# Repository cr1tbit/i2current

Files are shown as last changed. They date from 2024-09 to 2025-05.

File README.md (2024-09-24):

# I2Current powerboard

The Raison d'être of this board is to be a powerful, extensible, and affordable replacement for hotglueing a random powerbank into your next portable small-scale electronic project.

The largest benefit comes from the I2C interface - If, for example, a Raspberry Pi is powered with this board, it can actually check the battery state, if DC-jack is currently charging the device, or even see the power draw of other peripherals connected to this system.

The board is most useful for powering devices requiring peak power draw between 15W-60W.

For devices requiring less power, the cost overhead becomes a bit too much - alternative solutions on aliexpress, albeit not as much versatile, can cost less than $3 (this board costs ~$10, ordering 20 units from JLCPCB).

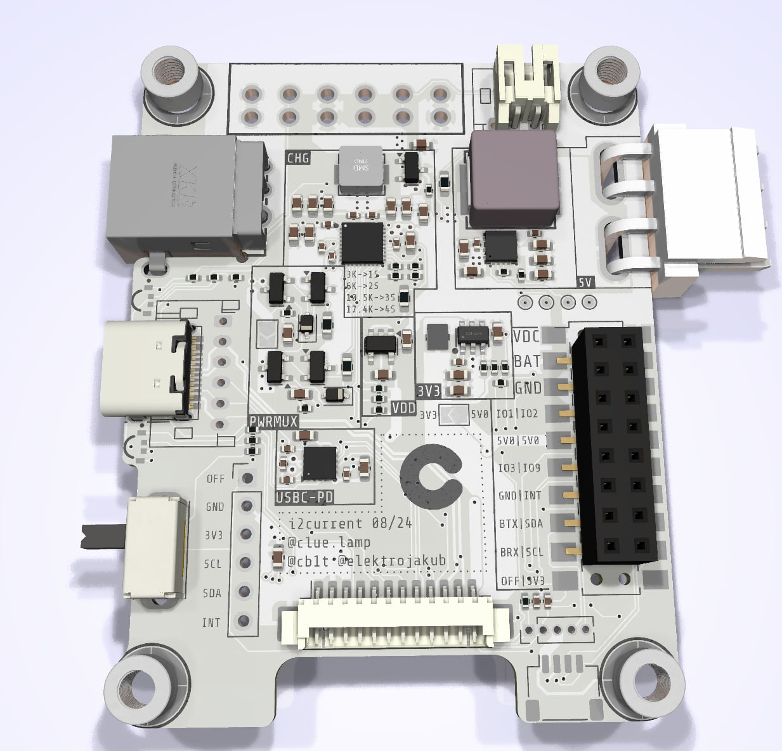
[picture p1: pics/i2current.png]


## Sub-components

### BQ25792 Li-Ion charger

Specs:

* 3.6-24V input, max 3A (realistically, ~60W)
* Input voltage independent from battery pack (buck-boost built-in)
* Input from USB-C and/or DC barrel jack.
* Can provide up to 3.33A@20V output to the same USB-C port
* can work with 1S-4S (cells in series)
* output current 5A (with 4 cells (~16V), up to ~80W output)
* Works properly without battery pack too (can work as buck-boost power supply)
* Many parameters configurable via i2c
* Various battery/input/output voltages/currents readout

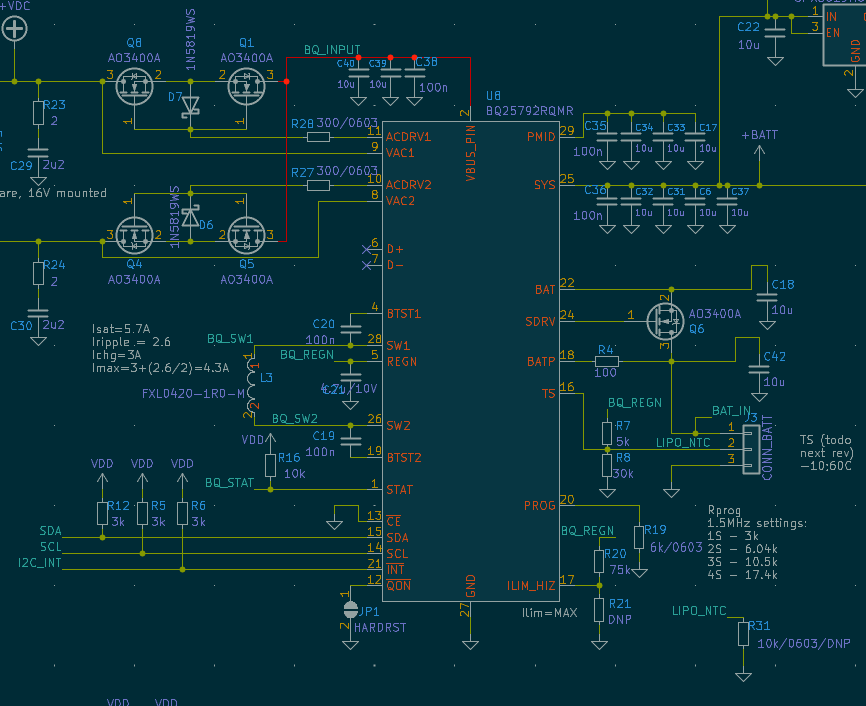
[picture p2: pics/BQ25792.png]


This charger is incredibly universal, costing around 1$ it provides versatility for many types of projects.

### TPS56637 5V output step-down converter

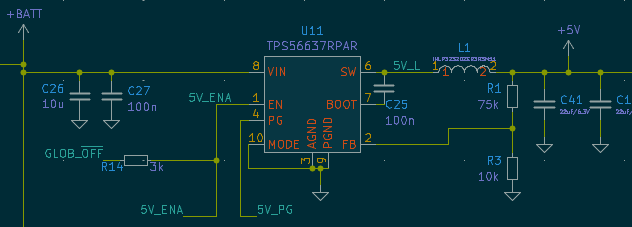
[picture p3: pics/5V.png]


It can provide up to 6A (30W) on output. However, it requires atleast 2S packet to be usable.

### MT2492 3V3 DC-DC

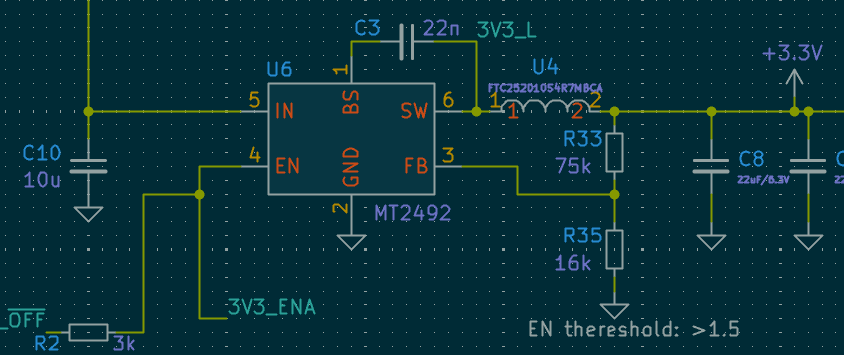
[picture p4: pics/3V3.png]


This converter supports optional built-in ESP32-C3 controller, and can also be accesed via output pins

### SPX3819M5-L-3-3 3V3 LDO

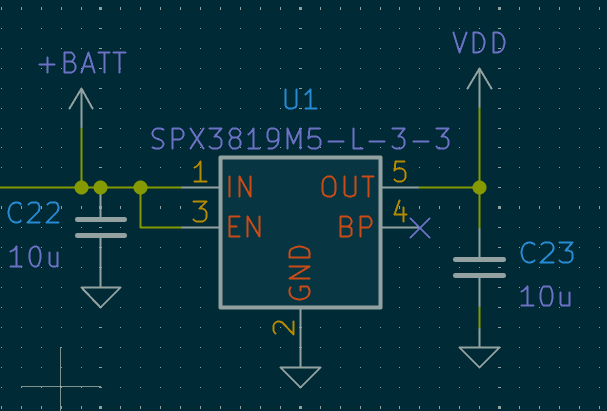
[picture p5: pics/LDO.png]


This low-power stabilizer provides power to onboard devices and some circuitry. It cannot be turned off, in contrast to 2 other converters.

### FUSB302B Power Delivery controller

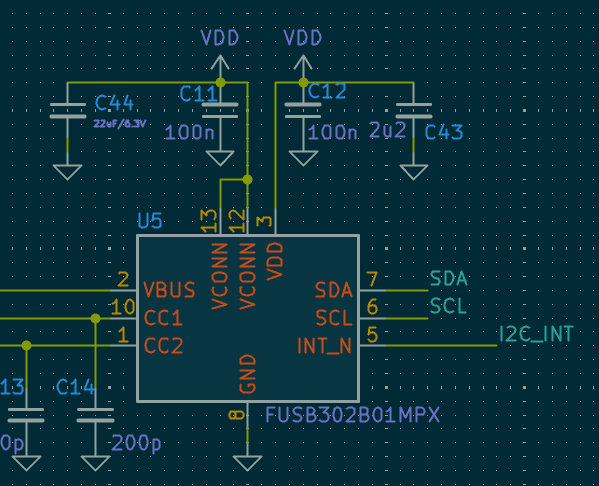
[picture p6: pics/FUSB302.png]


This device is controlled via i2c, and can be used to negotiate up to 5A/20V from compatible USB-C chargers.

Arduino library is available.

## Connectors

### Output 2.54 connector

This connector has been designed for low-profile goldpin socket connector (the male header actually goes through the holes in the PCB)

Shield can be designed, utilizing this connector.

### Picoblade connector

This connector is dedicated for devices, where a "master" board sits somewhere else in the system. 

### Battery connector

* Battery input
* NTC resistor input (every battery pack should contain one, more on that later)
* GND
* Battery output (coming from BQ charger, provides stable voltage when baterry is depleated or missing)
* GLOB_OFF (pin for external power-off switch)
* VDC_IN (same as from barrel jack input)

## More to come...

this board has many more fun quirks - I'll describe more details at a later date.

* optional mini front panel with OLED
* Passive-PoE input
* standalone 4-channel WLED controller
* USB data lanes passthrough for 2 connectors and built-in ESP32

#### Todo - document:

* Li-ion safety guide
* USB passthrough
* GLOB_OFF usage
* Pinout description for every connector
* 1S-4S config and limitations

## Sponsors

Developent of this board is supported by [Clue.lamp](https://www.instagram.com/clue.lamp/).

Check them out, the device looks really nice, and utilizes state-of-the-art electronic design for both wired and wireless usage :)

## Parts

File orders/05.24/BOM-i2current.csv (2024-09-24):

Comment | Designator | Footprint | LCSC
6k/0603 | R19 | R_0603_1608Metric_Pad0.98x0.95mm_HandSolder | C131439
FUSB302B01MPX | U5 | WQFN-14-1EP_2.5x2.5mm_P0.5mm_EP1.45x1.45mm | C132291
200p | C13,C14 | C_0402_1005Metric | C1530
22n | C3 | C_0402_1005Metric | C1532
2u2 | C29,C30,C43 | C_0603_1608Metric | C15849
USB_C_Receptacle_USB2.0 | J2 | USB_C_Receptacle_HRO_TYPE-C-31-M-12 | C165948
FXL0420-1R0-M | L3 | IND-SMD_L4.4-W4.2 | C167203
1N5819WS | D6,D7 | D_SOD-323 | C191023
4.7u/10V | C21 | C_0402_1005Metric | C19702
AO3400A | Q1,Q4,Q5,Q6,Q8 | SOT-23 | C20917
300/0603 | R27,R28 | R_0603_1608Metric_Pad0.98x0.95mm_HandSolder | C23025
100 | R11,R4 | R_0402_1005Metric | C25076
2 | R23,R24 | R_0402_1005Metric | C25092
30k | R8 | R_0402_1005Metric | C25553
10k | R10,R16,R3,R9 | R_0402_1005Metric | C25744
16k | R35 | R_0402_1005Metric | C25759
75k | R1,R20,R33 | R_0402_1005Metric | C25798
3k | R12,R14,R18,R2,R25,R29,R5,R6 | R_0402_1005Metric | C25890
5k | R7 | R_0402_1005Metric | C25905
Conn_01x12_MountingPin | J4 | Molex_PicoBlade_53261-1271_1x12-1MP_P1.25mm_Horizontal | C276921
BQ25792RQMR | U8 | QFN-29_L4.0-W4.0-P0.40-TL-BQ25792RQMR | C2862876
SMTSO3030CTJ | U10,U2,U3,U9 | SMD_BD5.6-D4.1 | C2915308
100n | C1,C11,C12,C19,C2,C20,C25,C27,C35,C36,C38 | C_0402_1005Metric | C307331
SW_SPDT | SW6 | SW_Slide_SPDT_Angled_CK_OS102011MA1Q | C393937
DC-C033D-5.5A-2.0 | DC1 | DC-IN-TH_DC-C033D-5.5A-2.5 | C500113
IHLP3232DZER3R3M11 | L1 | IND-SMD_L8.7-W8.2_IHLP-3232CZ | C511015
A-SP1102AR6GHC-A01-2C | U12,U13 | LED-SMD_4P-L3.0-W1.5_A-SP1102AR6GHC-A01-2C | C5160724
FTC252010S4R7MBCA | U4 | IND-SMD_L2.5-W2.0-VLS252012CX-150M | C5832360
22uF/6.3V | C15,C4,C41,C44,C8,C9 | C_0603_1608Metric | C59461
TPS56637RPAR | U11 | VQFN-HR-10_L3.0-W3.0_RPA | C841386
MT2492 | U6 | SOT-23-6_L2.9-W1.6-P0.95-LS2.8-BL | C89358
SPX3819M5-L-3-3 | U1 | SOT-23-5 | C9055
10u | C10,C17,C18,C22,C23,C26,C31,C32,C33,C34,C37,C39,C40,C42,C5,C6 | C_0603_1608Metric | C96446
PANEL_CONN | J8 | PinHeader_1x06_P2.54mm_Vertical
EXT_IFACE | J5 | 2x10_smdthrough
CONN_BATT | J3 | JST_PH_S3B-PH-K_1x03_P2.00mm_Horizontal
Conn_01x06 | J9 | JST_PH_S6B-PH-K_1x06_P2.00mm_Horizontal
Conn_01x05 | J6 | PinHeader_1x05_P1.27mm_Vertical
B4P | J1 | B4P_MATRIXPWR
DNP | R21 | R_0402_1005Metric
QWIIC | J10 | JST_SH_SM04B-SRSS-TB_1x04-1MP_P1.00mm_Horizontal
HARDRST | JP1 | SolderJumper-2_P1.3mm_Open_TrianglePad1.0x1.5mm
QWIIC | J11 | JST_SH_SM04B-SRSS-TB_1x04-1MP_P1.00mm_Horizontal
TestPoint | TP1 | TestPoint_Pad_D1.0mm
ESP32-C3-WROOM-02 | U7 | ESP32-C3-WROOM-02
TestPoint | TP3 | TestPoint_Pad_D1.0mm
TestPoint | TP2 | TestPoint_Pad_D1.0mm
JL15EDGA-38106G01 | CN1 | CONN-TH_6P-P3.81_JILN_JL15EDGA-38106G01
VBUS_DC | JP3 | SolderJumper-2_P1.3mm_Open_TrianglePad1.0x1.5mm
10k/0603/DNP | R31 | R_0603_1608Metric_Pad0.98x0.95mm_HandSolder
3V3_5V | JP4 | SolderJumper-2_P1.3mm_Open_TrianglePad1.0x1.5mm
TestPoint | TP4 | TestPoint_Pad_D1.0mm

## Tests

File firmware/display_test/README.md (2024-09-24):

# i2current firmware project

Not much to talk here for now. Tested utils:

* PD controller - negotiation works fine, but only if set up properly. In other case, it can cause the device to bootloop.
* BQ charger - the library provides only some of the features, but they seem to work fine.

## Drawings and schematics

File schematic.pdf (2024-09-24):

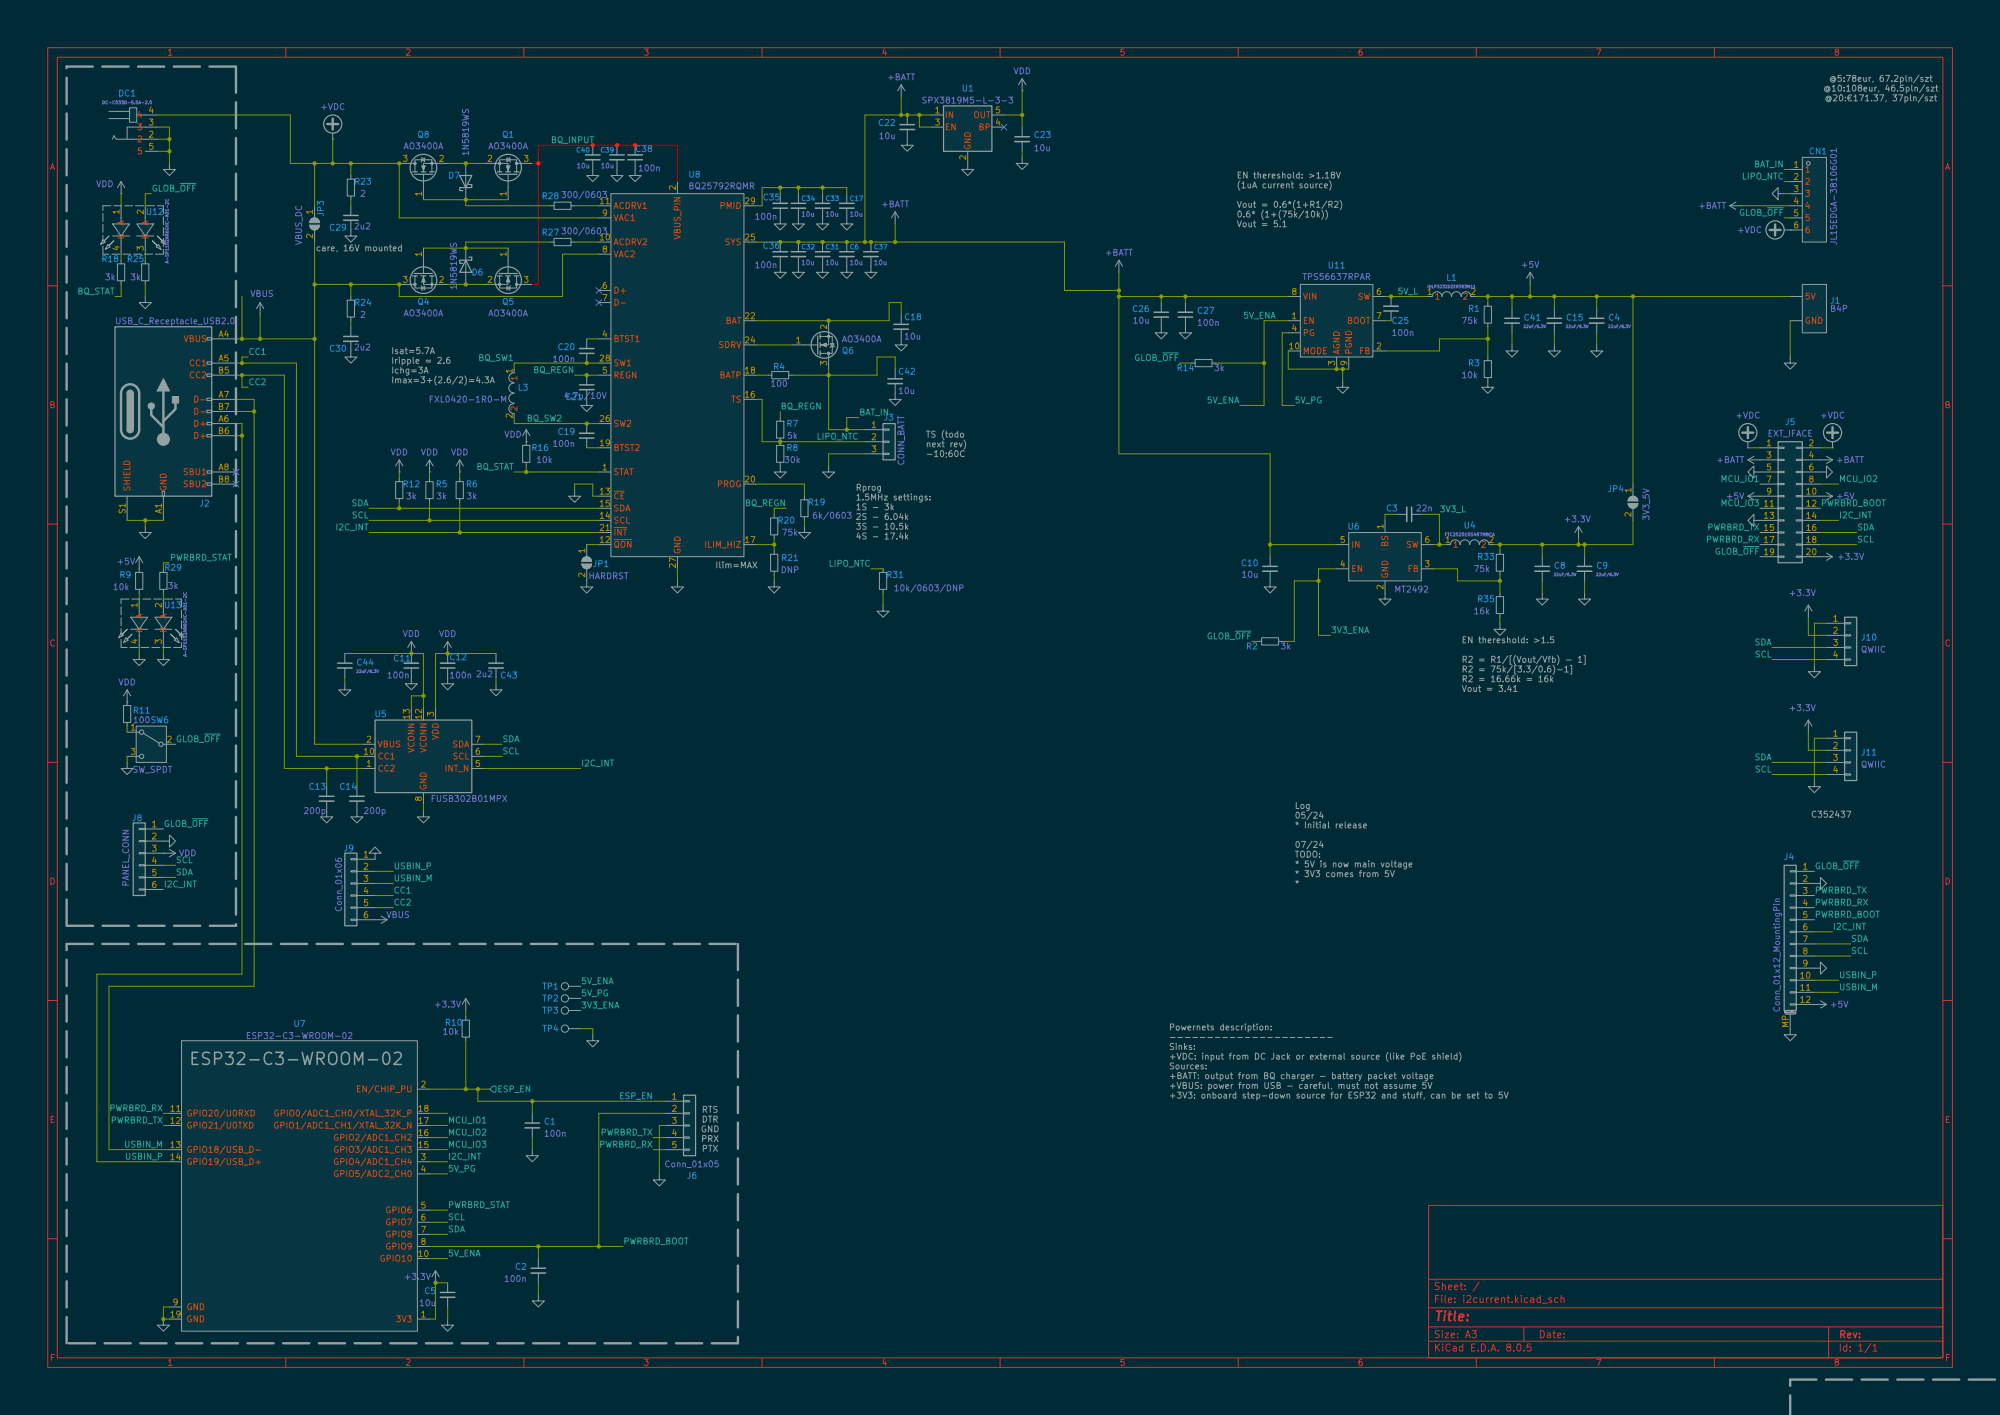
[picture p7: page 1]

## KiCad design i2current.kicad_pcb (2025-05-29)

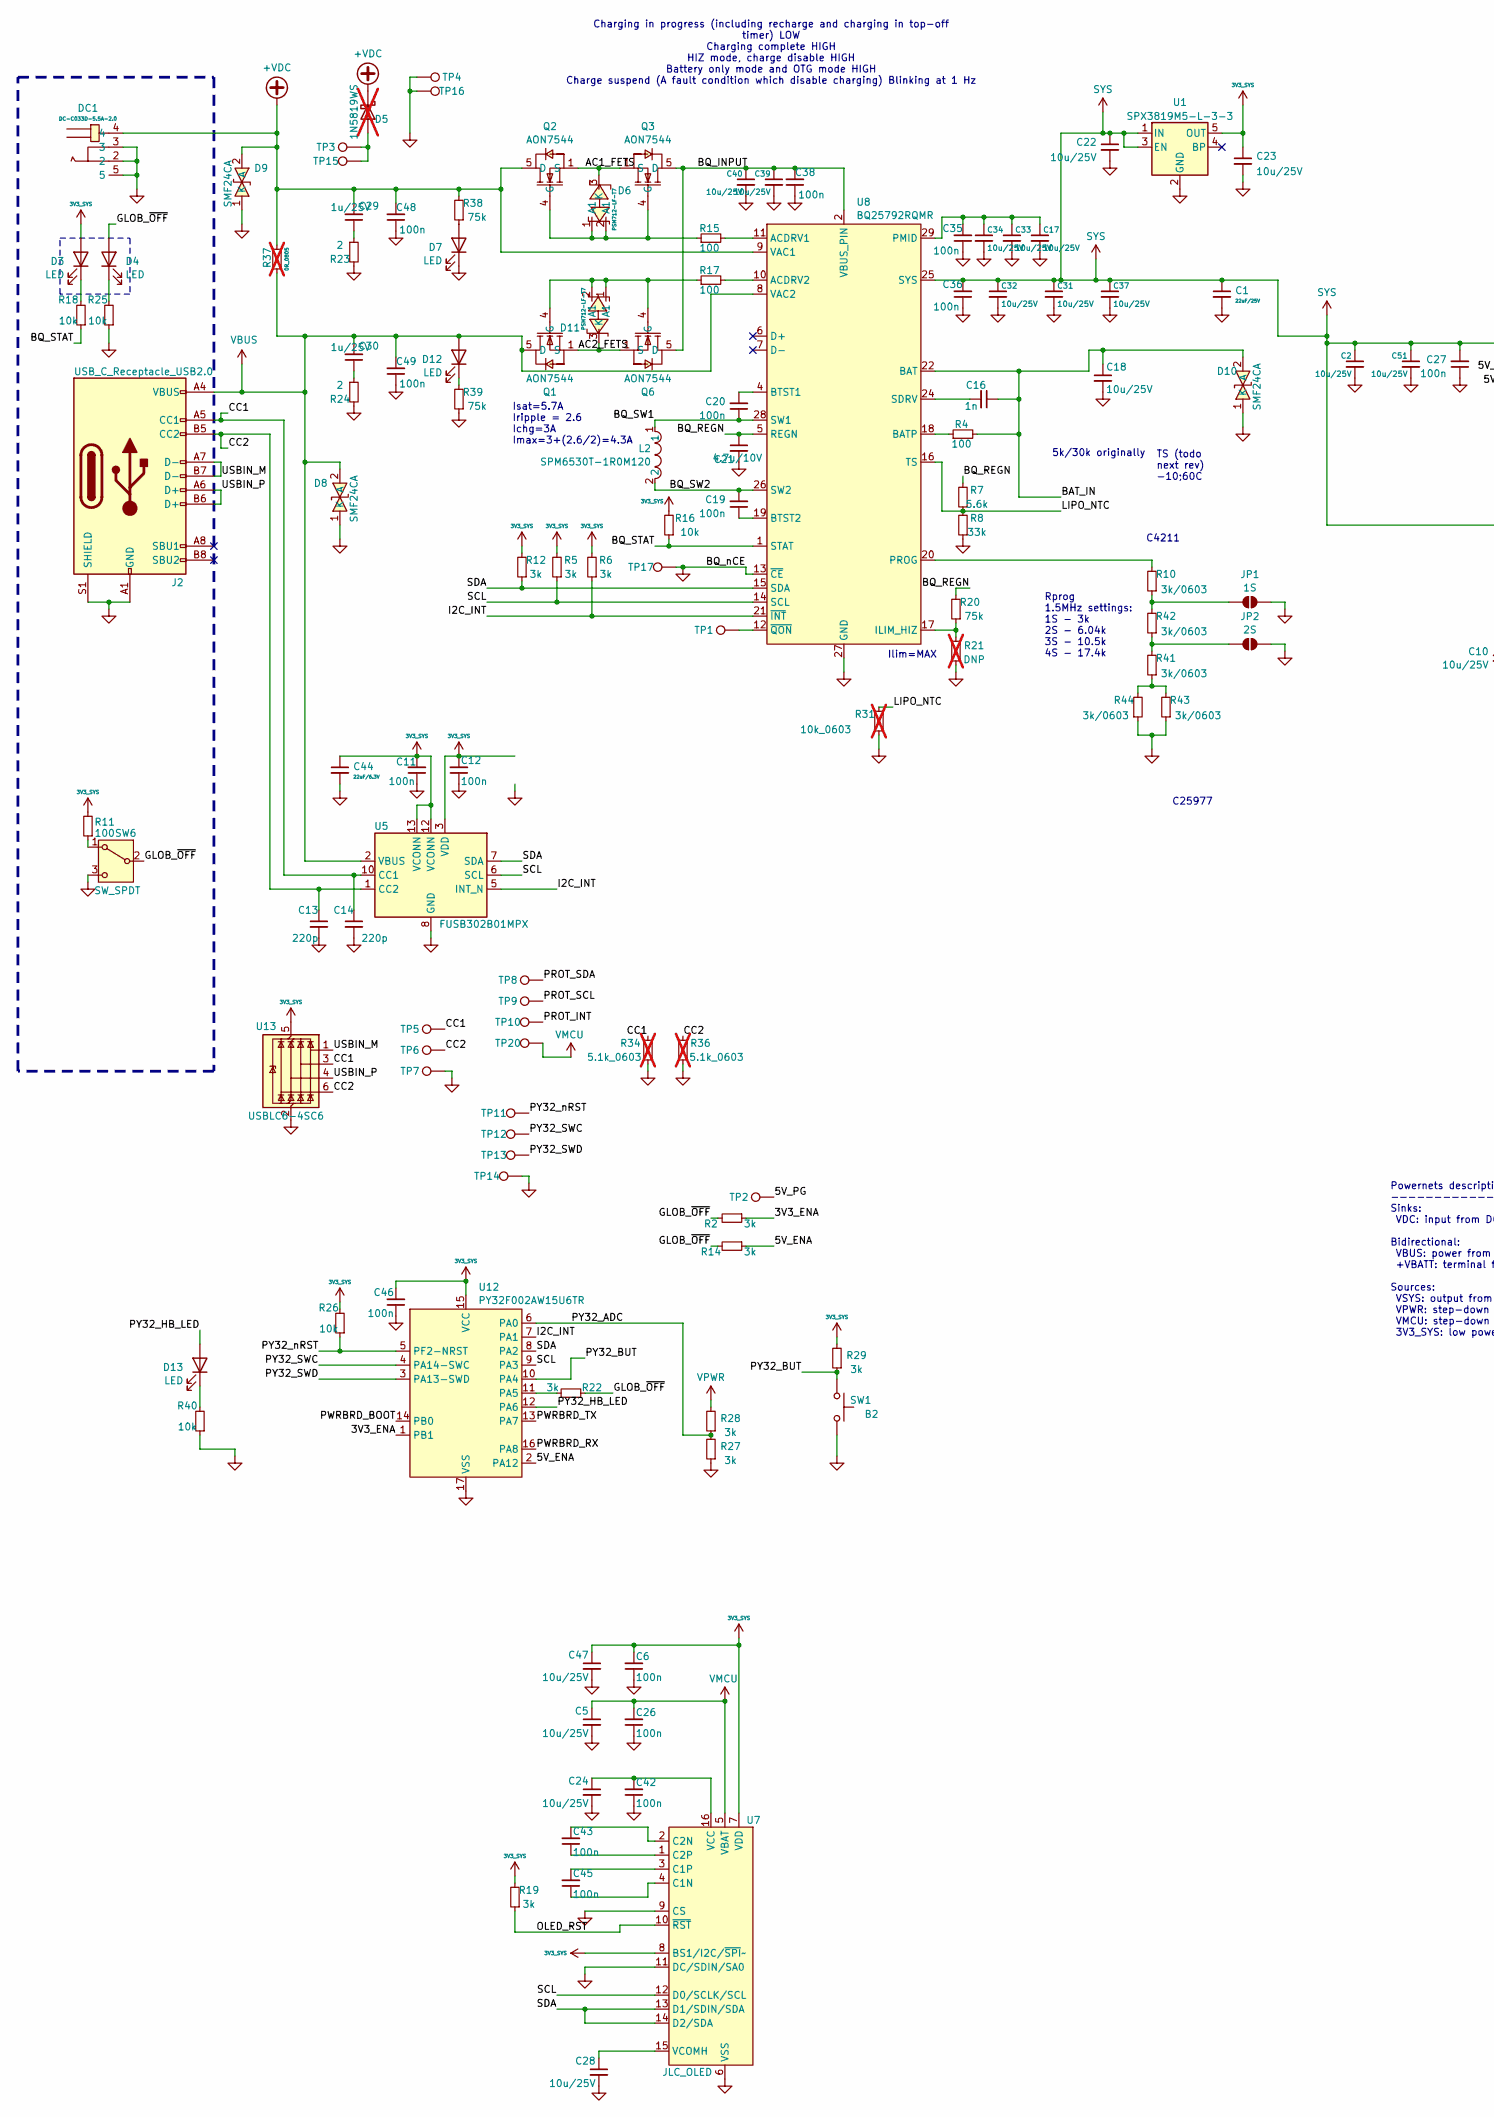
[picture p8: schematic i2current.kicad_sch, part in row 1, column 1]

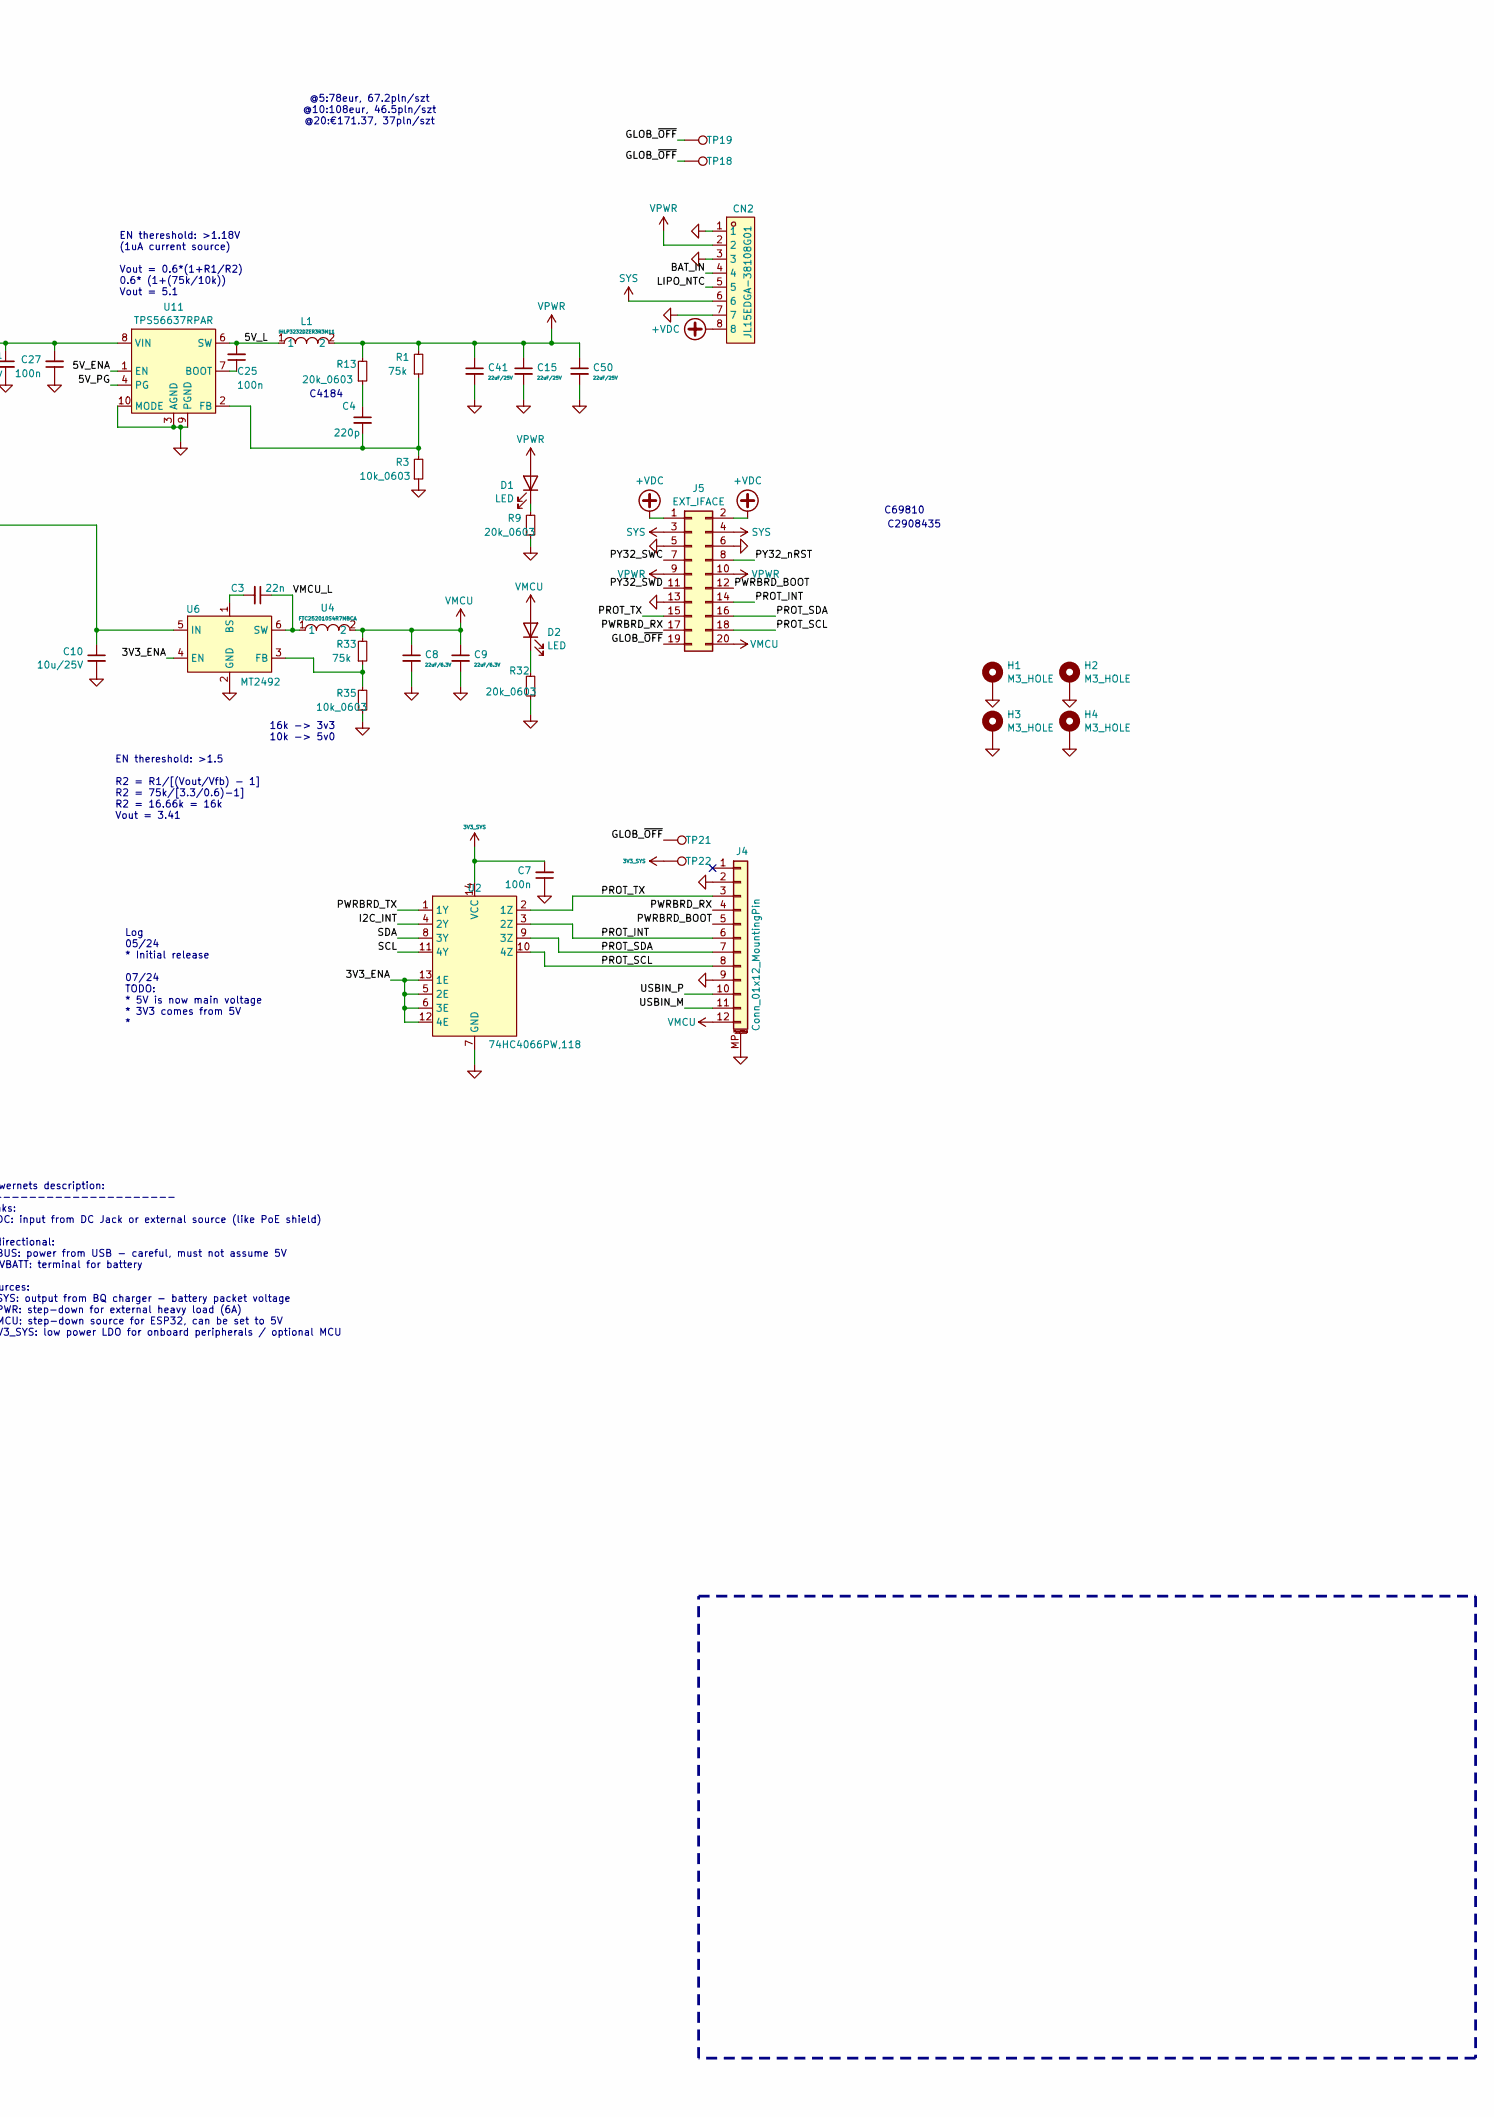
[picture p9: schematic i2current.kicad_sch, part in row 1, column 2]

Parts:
C1, C15, C41, C50: 22uF/25V; C_1206_3216Metric; LCSC C12891
C2, C5, C10, C17, C18, C22, C23, C24, C28, C31, C32, C33, C34, C37, C39, C40, C47, C51: 10u/25V; C_0603_1608Metric; LCSC C96446
C3: 22n; C_0402_1005Metric; LCSC C1532
C4, C13, C14: 220p; C_0402_1005Metric; LCSC C1530
C6, C7, C11, C12, C19, C20, C25, C26, C27, C35, C36, C38, C42, C43, C45, C46, C48, C49: 100n; C_0402_1005Metric; LCSC C307331
C8, C9, C44: 22uF/6.3V; C_0603_1608Metric; LCSC C59461
C16: 1n; C_0402_1005Metric; LCSC C1532
C21: 4.7u/10V; C_0402_1005Metric; LCSC C23733
C29, C30: 1u/25V; C_0603_1608Metric; LCSC C15849
CN2: JL15EDGA-38108G01; CONN-TH_8P-P3.81_JILN_JL15EDGA-38108G01; LCSC Part C2908436
D1, D2, D3, D4, D7, D12, D13: LED; LED_0603_1608Metric; LCSC C72038
D5: 1N5819WS; D_SOD-323; LCSC C191023; not fitted
D6, D11: PSM712-LF-T7; SOT-23-3_L3.0-W1.7-P0.95-LS2.9-BR; LCSC C32677
D8, D9, D10: SMF24CA; SOD-123FL_L2.7-W1.8-LS3.8-BI; LCSC C19077515
DC1: DC-C033D-5.5A-2.0; DC-IN-TH_DC-C033D-5.5A-2.5; LCSC C500113
H1, H2, H3, H4: M3_HOLE; MountingHole_3.2mm_LONGE
J2: USB_C_Receptacle_USB2.0; USB_C_Receptacle_HRO_TYPE-C-31-M-12; LCSC C165948
J4: Conn_01x12_MountingPin; Molex_PicoBlade_53261-1271_1x12-1MP_P1.25mm_Horizontal; LCSC C276921
J5: EXT_IFACE; SAMTEC_HLE-110-02-F-DV-BE-A
JP1: 1S; SolderJumper-2_P1.3mm_Open_TrianglePad1.0x1.5mm
JP2: 2S; SolderJumper-2_P1.3mm_Open_TrianglePad1.0x1.5mm
L1: IHLP3232DZER3R3M11; IND-SMD_L8.7-W8.2_IHLP-3232CZ; LCSC C511015
L2: SPM6530T-1R0M120; IND-SMD_L7.1-W6.5-P5.60; LCSC C87572
Q1, Q2, Q3, Q6: AON7544; DFN-8_L3.3-W3.3-P0.65-BL-2; LCSC C315567
R1, R20, R33, R38, R39: 75k; R_0603_1608Metric
R2, R5, R6, R12, R14, R19, R22, R27, R28, R29: 3k; R_0402_1005Metric
R3, R35: 10k_0603; R_0603_1608Metric
R4, R11, R15, R17: 100; R_0402_1005Metric
R7: 5.6k; R_0603_1608Metric
R8: 33k; R_0603_1608Metric
R9, R13, R32: 20k_0603; R_0603_1608Metric
R10, R41, R42, R43, R44: 3k/0603; R_0603_1608Metric
R16, R18, R25, R26, R40: 10k; R_0402_1005Metric
R21: DNP; R_0603_1608Metric; not fitted
R23, R24: 2; R_0603_1608Metric; LCSC C22939
R31: 10k_0603; R_0603_1608Metric; not fitted
R34, R36: 5.1k_0603; R_0603_1608Metric; not fitted
R37: 0R_0805; R_0805_2012Metric; not fitted
SW1: B2; SW_SPST_TL3342; LCSC C318884
SW6: SW_SPDT; SW_Slide_SPDT_Angled_CK_OS102011MA1Q; LCSC C393937
TP1, TP17, TP18, TP19, TP21, TP22: TestPoint; Nano_testpad_0.5x1.0mm
TP2, TP5, TP6, TP7, TP8, TP9, TP10, TP11, TP12, TP13, TP14, TP20: TestPoint; TestPoint_Pad_D1.0mm
TP3, TP4, TP15, TP16: TestPoint; TestPoint_Pad_D2.0mm
U1: SPX3819M5-L-3-3; SOT-23-5; LCSC C9055
U2: 74HC4066PW,118; TSSOP-14_L5.0-W4.4-P0.65-LS6.4-BL; LCSC C5650
U4: FTC252010S4R7MBCA; IND-SMD_L2.5-W2.0-VLS252012CX-150M; LCSC C5832360
U5: FUSB302B01MPX; WQFN-14-1EP_2.5x2.5mm_P0.5mm_EP1.45x1.45mm; LCSC C442699
U6: MT2492; SOT-23-6_L2.9-W1.6-P0.95-LS2.8-BL; LCSC C89358
U7: JLC_OLED; OLED-042-JLC
U8: BQ25792RQMR; QFN-29_L4.0-W4.0-P0.40-TL-BQ25792RQMR; LCSC C2862876
U11: TPS56637RPAR; VQFN-HR-10_L3.0-W3.0_RPA; LCSC C841386
U12: PY32F002AW15U6TR; TQFN-16-1EP_3x3mm_P0.5mm_EP1.6x1.6mm; LCSC C5291740
U13: USBLC6-4SC6; SOT-23-6; LCSC C5197386

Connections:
3V3_SYS: C6.2, C7.2, C11.2, C12.2, C23.1, C44.1, C46.2, C47.1, D3.2 (A), R5.2, R6.2, R11.2, R12.2, R16.2, R19.2, R26.2, R29.2, TP22.1, U1.5 (OUT), U2.14 (VCC), U5.3 (VDD), U5.4 (VDD), U5.12 (VCONN), U5.13 (VCONN), U7.7 (VDD), U7.8 (BS1/I2C/~SPI~), U12.15 (VCC), U13.5 (VBUS)
+VDC: C29.2, C48.2, CN2.8, D5.1 (K), D9.2 (A), DC1.4, J5.1, J5.2, Q2.5 (D), R37.1, R38.2, U8.9 (VAC1)
/3V3_ENA: R2.1, U2.5 (2E), U2.6 (3E), U2.12 (4E), U2.13 (1E), U6.4 (EN), U12.1 (PB1)
/5V_ENA: R14.1, U11.1 (EN), U12.2 (PA12)
/5V_L: C25.2, L1.1, U11.6 (SW)
/5V_PG: TP2.1, U11.4 (PG)
/AC1_FETS: D6.3 (K), Q2.1 (S), Q2.2 (S), Q2.3 (S), Q3.1 (S), Q3.2 (S), Q3.3 (S)
/AC2_FETS: D11.3 (K), Q1.1 (S), Q1.2 (S), Q1.3 (S), Q6.1 (S), Q6.2 (S), Q6.3 (S)
/BQ_REGN: C21.1, R7.2, R20.2, U8.5 (REGN)
/BQ_STAT: R16.1, R18.1, U8.1 (STAT)
/BQ_SW1: C20.1, L2.1, U8.28 (SW1)
/BQ_SW2: C19.2, L2.2, U8.26 (SW2)
/CC1: C14.1, J2.A5 (CC1), R34.1, TP5.1, U5.10 (CC1), U5.11 (CC1), U13.3 (I/O2)
/CC2: C13.1, J2.B5 (CC2), R36.1, TP6.1, U5.1 (CC2), U5.14 (CC2), U13.6 (I/O4)
/GLOB_~OFF: D4.2 (A), J5.19, R2.2, R14.2, R22.2, SW6.2 (B), TP18.1, TP19.1, TP21.1
/I2C_INT: R6.1, U2.4 (2Y), U5.5 (INT_N), U8.21 (~INT), U12.7 (PA1)
/LIPO_NTC: CN2.5, R7.1, R8.2, R31.2, U8.16 (TS)
/OLED_RST: R19.1, U7.10 (~RST)
/PROT_INT: J4.6, J5.14, TP10.1, U2.3 (2Z)
/PROT_SCL: J4.8, J5.18, TP9.1, U2.10 (4Z)
/PROT_SDA: J4.7, J5.16, TP8.1, U2.9 (3Z)
/PROT_TX: J4.3, J5.15, U2.2 (1Z)
/PWRBRD_BOOT: J4.5, J5.12, U12.14 (PB0)
/PWRBRD_RX: J4.4, J5.17, U12.16 (PA8)
/PWRBRD_TX: U2.1 (1Y), U12.13 (PA7)
/PY32_ADC: R27.2, R28.1, U12.6 (PA0)
/PY32_BUT: R29.1, SW1.2, U12.10 (PA4)
/PY32_HB_LED: D13.2 (A), U12.12 (PA6)
/PY32_SWC: J5.7, TP12.1, U12.4 (PA14-SWC)
/PY32_SWD: J5.11, TP13.1, U12.3 (PA13-SWD)
/PY32_nRST: J5.8, R26.1, TP11.1, U12.5 (PF2-NRST)
/SCL: R5.1, U2.11 (4Y), U5.6 (SCL), U7.12 (D0/SCLK/SCL), U8.14 (SCL), U12.9 (PA3)
/SDA: R12.1, U2.8 (3Y), U5.7 (SDA), U7.13 (D1/SDIN/SDA), U7.14 (D2/SDA), U8.15 (SDA), U12.8 (PA2)
/USBIN_M: J2.A7 (D-), J2.B7 (D-), J4.11, U13.1 (I/O1)
/USBIN_P: J2.A6 (D+), J2.B6 (D+), J4.10, U13.4 (I/O3)
/VMCU_L: C3.1, U4.1, U6.6 (SW)
BAT: C16.1, C18.1, CN2.4, D10.2 (A), R4.2, U8.22 (BAT), U8.23 (BAT)
GND: C1.2, C2.2, C5.2, C6.1, C7.1, C8.2, C9.2, C10.2, C11.1, C12.1, C13.2, C14.2, C15.2, C17.2, C18.2, C21.2, C22.2, C23.2, C24.2, C26.1, C27.1, C28.2, C31.2, C32.2, C33.2, C34.2, C35.1, C36.1, C37.2, C38.1, C39.2, C40.2, C41.2, C42.1, C44.2, C46.1, C47.2, C48.1, C49.1, C50.2, C51.2, CN2.1, CN2.3, CN2.7, D7.1 (K), D8.1 (K), D9.1 (K), D10.1 (K), DC1.2, DC1.3, DC1.5, H1.1, H2.1, H3.1, H4.1, J2.A1 (GND), J2.A12 (GND), J2.B1 (GND), J2.B12 (GND), J2.S1 (SHIELD), J4.2, J4.9, J4.MP (MountPin), J5.5, J5.6, J5.13, JP1.2 (B), JP2.2 (B), R3.1, R8.1, R9.1, R21.1, R23.2, R24.2, R25.1, R27.1, R31.1, R32.1, R34.2, R35.1, R36.2, R39.1, R40.1, R43.1, R44.1, SW1.1, SW6.3 (C), TP4.1, TP7.1, TP14.1, TP16.1, TP17.1, U1.2 (GND), U2.7 (GND), U5.8 (GND), U5.9 (GND), U5.15 (GND), U6.2 (GND), U7.6 (VSS), U7.9 (CS), U7.11 (DC/SDIN/SA0), U8.13 (~CE), U8.27 (GND), U11.3 (AGND), U11.9 (PGND), U11.10 (MODE), U12.17 (VSS), U13.2 (GND)
unnamed: C4.1, R13.1
unnamed: C29.1, R23.1
unnamed: C30.1, R24.1
unnamed: D1.1 (K), R9.2
unnamed: D2.1 (K), R32.2
unnamed: D3.1 (K), R18.2
unnamed: D4.1 (K), R25.2
unnamed: D5.2 (A), TP3.1, TP15.1
unnamed: D7.2 (A), R38.1
unnamed: D12.1 (K), R39.2
unnamed: D13.1 (K), R40.2
unnamed: JP1.1 (A), R10.1, R42.2
unnamed: JP2.1 (A), R41.2, R42.1
unnamed: D11.1 (A1), D11.2 (A1), Q1.4 (G), Q6.4 (G), R17.1
unnamed: D6.1 (A1), D6.2 (A1), Q2.4 (G), Q3.4 (G), R15.1
unnamed: R41.1, R43.2, R44.2
unnamed: R11.1, SW6.1 (A)
unnamed: C3.2, U6.1 (BS)
unnamed: R33.1, R35.2, U6.3 (FB)
unnamed: C45.1, U7.4 (C1N)
unnamed: C45.2, U7.3 (C1P)
unnamed: C43.2, U7.2 (C2N)
unnamed: C43.1, U7.1 (C2P)
unnamed: C24.1, C42.2, U7.16 (VCC)
unnamed: C28.1, U7.15 (VCOMH)
unnamed: R15.2, U8.11 (ACDRV1)
unnamed: R17.2, U8.10 (ACDRV2)
unnamed: R4.1, U8.18 (BATP)
unnamed: C20.2, U8.4 (BTST1)
unnamed: C19.1, U8.19 (BTST2)
unnamed: R20.1, R21.2, U8.17 (ILIM_HIZ)
unnamed: C17.1, C33.1, C34.1, C35.2, U8.29 (PMID)
unnamed: R10.2, U8.20 (PROG)
unnamed: C16.2, U8.24 (SDRV)
unnamed: TP1.1, U8.12 (~QON)
unnamed: C25.1, U11.7 (BOOT)
unnamed: C4.2, R1.1, R3.2, U11.2 (FB)
unnamed: R22.1, U12.11 (PA5)
SYS: C1.1, C2.1, C10.1, C22.1, C27.2, C31.1, C32.1, C36.2, C37.1, C51.1, CN2.6, J5.3, J5.4, U1.1 (IN), U1.3 (EN), U6.5 (IN), U8.25 (SYS), U11.8 (VIN)
VBUS: C30.2, C49.2, D8.2 (A), D12.2 (A), J2.A4 (VBUS), J2.A9 (VBUS), J2.B4 (VBUS), J2.B9 (VBUS), Q1.5 (D), R37.2, U5.2 (VBUS), U8.8 (VAC2)
VBUS_PIN: C38.2, C39.1, C40.1, Q3.5 (D), Q6.5 (D), U8.2 (VBUS_PIN), U8.3 (VBUS_PIN)
VMCU: C5.1, C8.1, C9.1, C26.2, D2.2 (A), J4.12, J5.20, R33.2, TP20.1, U4.2, U7.5 (VBAT)
VPWR: C15.1, C41.1, C50.1, CN2.2, D1.2 (A), J5.9, J5.10, L1.2, R1.2, R13.2, R28.2

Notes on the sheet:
C2908435
C4184
16k -> 3v3 10k -> 5v0
C69810
Log 05/24 * Initial release 07/24 TODO: * 5V is now main voltage * 3V3 comes from 5V *
C25977
EN thereshold: >1.18V (1uA current source) Vout = 0.6*(1+R1/R2) 0.6* (1+(75k/10k)) Vout = 5.1
EN thereshold: >1.5 R2 = R1/[(Vout/Vfb) - 1] R2 = 75k/[3.3/0.6)-1] R2 = 16.66k = 16k Vout = 3.41
Isat=5.7A Iripple = 2.6 Ichg=3A Imax=3+(2.6/2)=4.3A
Powernets description: ---------------------- Sinks: VDC: input from DC Jack or external source (like PoE shield) Bidirectional: VBUS: power from USB - careful, must not assume 5V +VBATT: terminal for battery Sources: VSYS: output from BQ charger - battery packet voltage VPWR: step-down for externa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
Charging in progress (including recharge and charging in top-off timer) LOW Charging complete HIGH HIZ mode, charge disable HIGH Battery only mode and OTG mode HIGH Charge suspend (A fault condition which disable charging) Blinking at 1 Hz
Rprog 1.5MHz settings: 1S - 3k 2S - 6.04k 3S - 10.5k 4S - 17.4k
@5:78eur, 67.2pln/szt @10:108eur, 46.5pln/szt @20:€171.37, 37pln/szt
5k/30k originally
C4211
Ilim=MAX
TS (todo next rev) -10;60C

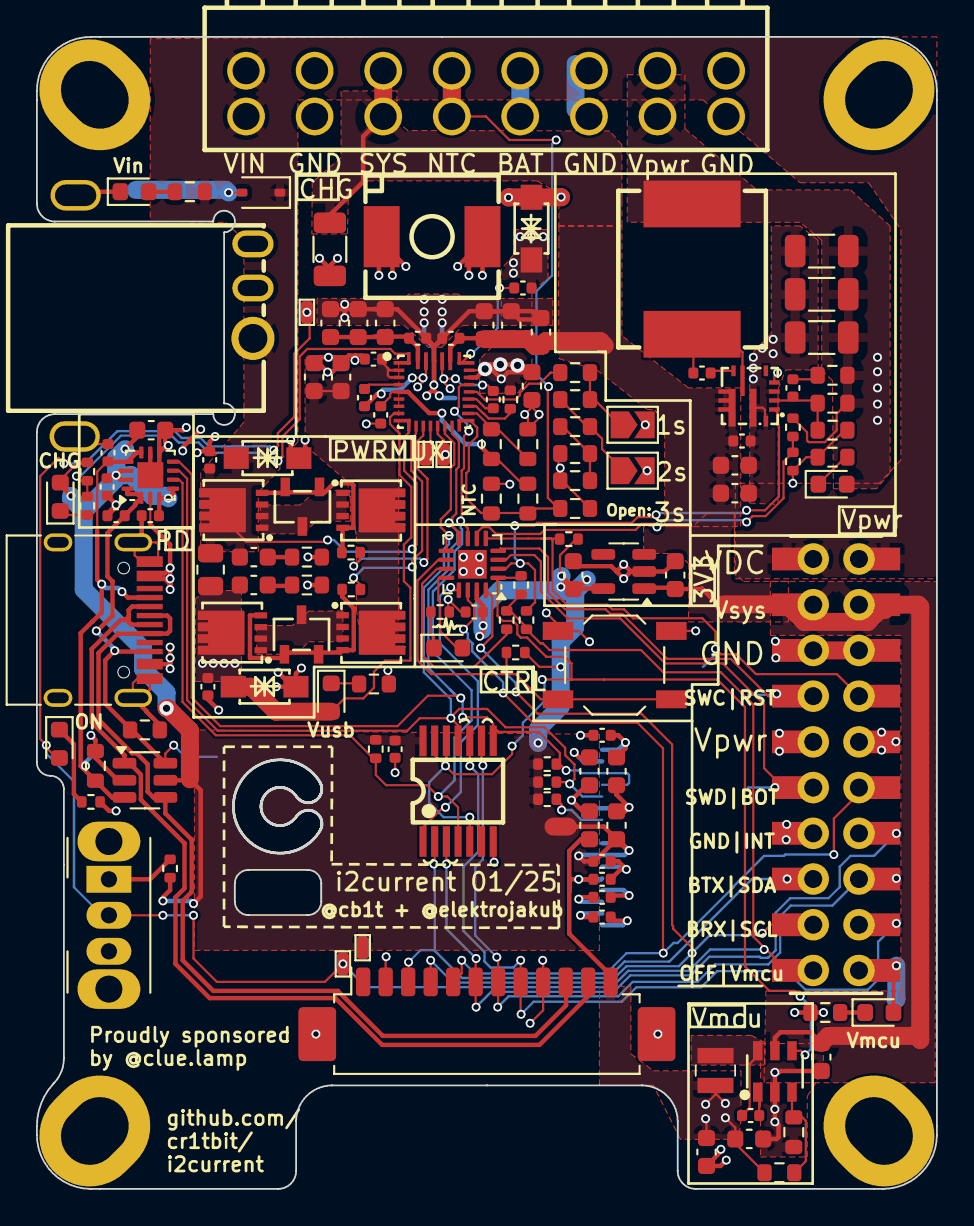
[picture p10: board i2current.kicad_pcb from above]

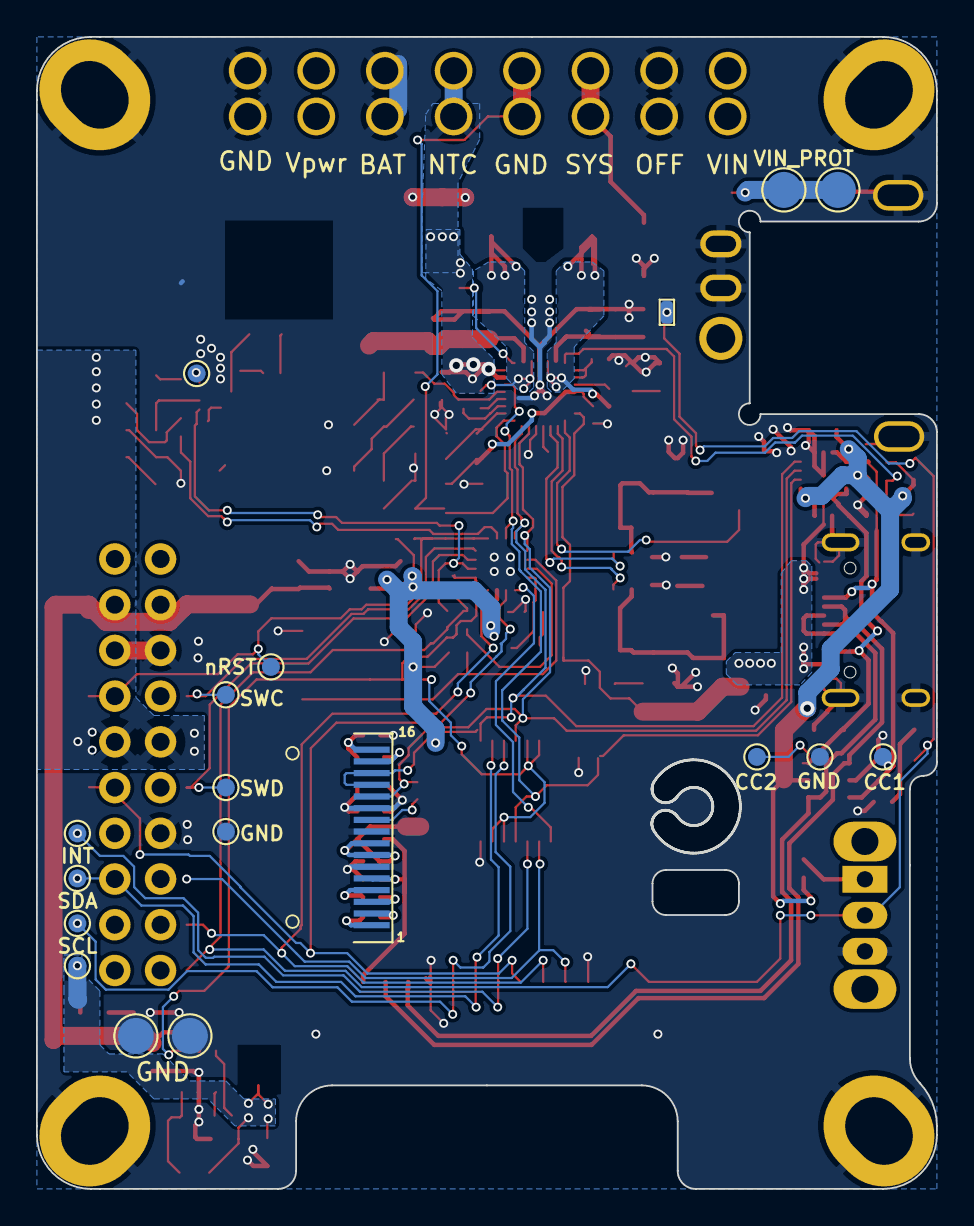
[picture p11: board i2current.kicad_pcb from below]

Board: 2 copper layers, 50.0 x 64.0 mm, 158 parts (18 on the bottom side), 81 nets.

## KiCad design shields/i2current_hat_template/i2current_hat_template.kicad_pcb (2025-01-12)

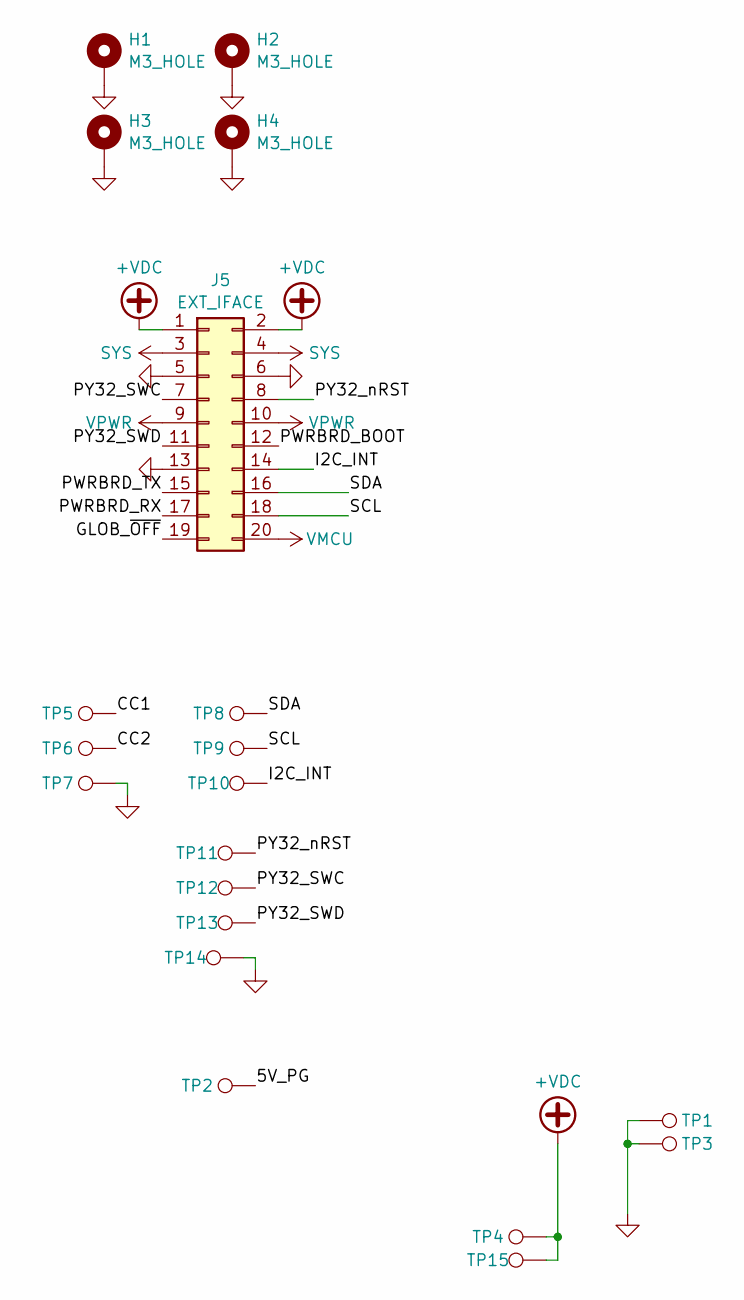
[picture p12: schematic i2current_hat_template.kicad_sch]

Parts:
H1, H2, H3, H4: M3_HOLE; MountingHole_3.2mm_M3_DIN965_Pad
J5: EXT_IFACE; PinHeader_2x10_P2.54mm_Vertical
TP1, TP3, TP4, TP15: TestPoint; TestPoint_Pad_D2.0mm
TP2, TP5, TP6, TP7, TP8, TP9, TP10, TP11, TP12, TP13, TP14: TestPoint; TestPoint_Pad_D1.0mm

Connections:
+VDC: J5.1, J5.2, TP4.1, TP15.1
/5V_PG: TP2.1
/CC1: TP5.1
/CC2: TP6.1
/GLOB_~OFF: J5.19
/I2C_INT: J5.14, TP10.1
/PWRBRD_BOOT: J5.12
/PWRBRD_RX: J5.17
/PWRBRD_TX: J5.15
/PY32_SWC: J5.7, TP12.1
/PY32_SWD: J5.11, TP13.1
/PY32_nRST: J5.8, TP11.1
/SCL: J5.18, TP9.1
/SDA: J5.16, TP8.1
GND: H1.1, H2.1, H3.1, H4.1, J5.5, J5.6, J5.13, TP1.1, TP3.1, TP7.1, TP14.1
SYS: J5.3, J5.4
VMCU: J5.20
VPWR: J5.9, J5.10

Board: 2 copper layers, 20 parts (0 on the bottom side), 10 nets, no tracks yet.

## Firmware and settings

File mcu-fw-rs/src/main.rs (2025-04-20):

#![no_std]
#![no_main]
#![feature(type_alias_impl_trait)]
#![feature(impl_trait_in_assoc_type)]

use defmt::*;
use embassy_executor::Spawner;

#[allow(unused)]
use embassy_time::{Duration, Timer, Ticker, Instant};

#[allow(unused)]
use py32_hal::{
    adc::{Adc, SampleTime},
    gpio::{Level, Pull, Speed},
    peripherals::{ADC, I2C1, USART1, PA0, PA1, PA2, PA3, PA4, PA5, PA6, PA7, PA8, PA12, PA13, PA14, PB0, PB1},
};
use {defmt_rtt as _, panic_probe as _};

// use cortex_m::peripheral::SCB;
use cortex_m_rt::{exception, ExceptionFrame};

mod bsp;
use bsp::pins::Board;
// use bsp::interrupts::Irqs;

#[embassy_executor::main]
async fn main(_spawner: Spawner) {
    info!("Hello World!");
    // Initialize board
    let mut board = Board::init();

    // Initialize battery monitor
    // let bat_monitor = bsp::bat::BatteryMonitor::new(board.adc, board.pins.pa0);

    // // Spawn battery monitor task
    // spawner.spawn(bsp::bat::run_bat_monitor(bat_monitor)).unwrap();

    board.i2c.scan();

    // Main loop
    let mut ticker = Ticker::every(Duration::from_secs(1));
    loop {
        ticker.next().await;
        info!("Tick");
    }
}

#[exception]
unsafe fn HardFault(_ef: &ExceptionFrame) -> ! {
    defmt::panic!("HardFault");
}

#[exception]
unsafe fn DefaultHandler(_irq: i16) {
    defmt::panic!("Unhandled exception ");
}

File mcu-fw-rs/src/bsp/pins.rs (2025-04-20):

// Please note, this code has been EXTREMELY vibecoded, and looks like shit.
// I only tested GPIO for now. Putting it on the repo for reference.

use py32_hal::{
    adc::{Adc, SampleTime},
    gpio::{Flex, Level, Pull, Speed},
    peripherals::ADC,
    rcc::{Pll, PllSource, Sysclk},
    time::Hertz,
    Peripheral, Peripherals,
};

use crate::bsp::{
    i2c::{I2cPeripheral},
    interrupts::Irqs,
};

/// Board Support Package for the PY32 MCU
#[allow(unused)]
pub struct Board<'a> {
    /// ADC peripheral
    pub adc: Adc<'a, ADC>,
    /// I2C peripheral
    pub i2c: I2cPeripheral<'a>,
    /// Available GPIO pins
    pub pins: ControlPins,
}

/// SWD debug pins
#[allow(unused)]
pub struct SwdPins {
    /// SWDIO pin
    pub swdio: Flex<'static>,
    /// SWCLK pin
    pub swclk: Flex<'static>,
}

// /// PA0 - ADC input
// /// PA1 - I2C interrupt
// /// PA2 - I2C SDA
// /// PA3 - I2C SCL
// /// PA4 - Battery charger chip select
// /// PA5 - OLED reset
// /// PA6 - Global power off
// /// PA7 - Power board UART TX
// /// PA8 - Power board UART RX
// /// PA12 - 5V enable
// /// PB0 - Power board boot
// /// PB1 - 3.3V enable

/// Available GPIO pins
#[allow(unused)]
pub struct ControlPins {
    pub chg_cs: Flex<'static>,   //CS
    pub oled_rst: Flex<'static>, //OLED rst
    pub glob_off: Flex<'static>, //GLOB_OFF
    pub ena_5v: Flex<'static>,   //5V ENA
    pub ena_3v3: Flex<'static>,  //3v3 ENA
}

impl<'a> Board<'a> {
    pub fn get_periph_handle() -> Peripherals {
        let mut cfg: py32_hal::Config = Default::default();
        cfg.rcc.hsi = Some(Hertz::mhz(24));
        cfg.rcc.pll = Some(Pll {
            src: PllSource::HSI,
        });
        cfg.rcc.sys = Sysclk::PLL;

        py32_hal::init(cfg)
    }

    /// Initialize the board and its peripherals
    pub fn init() -> Self {
        let p = Self::get_periph_handle();

        // Initialize GPIO pins
        let pins = ControlPins {
            chg_cs: Flex::new(p.PA4),
            oled_rst: Flex::new(p.PA5),
            glob_off: Flex::new(p.PA6),
            ena_5v: Flex::new(p.PA12),
            ena_3v3: Flex::new(p.PB1),
        };
        unsafe {
            // Initialize ADC
            let mut adc = Adc::new(p.ADC, Irqs);
            adc.set_sample_time(SampleTime::CYCLES71_5);

            // Initialize I2C
            let i2c = I2cPeripheral::new(
                p.I2C1,
                p.PA2.clone_unchecked(),
                p.PA3.clone_unchecked(),
                p.PA1.clone_unchecked(),
            );

            Self { adc, i2c, pins }
        }
    }
}

/// Helper functions for configuring pins
#[allow(unused)]
impl ControlPins {
    /// Configure a pin as output
    pub fn configure_output(&mut self, pin: &mut Flex<'static>, level: Level) {
        pin.set_as_output(Speed::VeryHigh);
        match level {
            Level::High => pin.set_high(),
            Level::Low => pin.set_low(),
        }
    }

    /// Configure a pin as input
    pub fn configure_input(&mut self, pin: &mut Flex<'static>, pull: Pull) {
        pin.set_as_input(pull);
    }
}

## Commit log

2024-04-12 save before charger replace
    [esp32-c3.kicad_sch, i2current.kicad_pcb, i2current.kicad_sch]
2024-04-23 connector placement
    [esp32-c3.kicad_sch, i2current.kicad_pcb, i2current.kicad_sch]
2024-05-04 do backup kids
    [esp32-c3.kicad_sch, i2current.kicad_pcb, i2current.kicad_sch]
2024-05-05 backup 2
    [esp32-c3.kicad_sch, i2current.kicad_pcb, i2current.kicad_sch]
2024-05-11 routing 2
    [i2current.kicad_pcb, i2current.kicad_sch]
2024-05-13 kinda finish route, needs some checks still
    [i2current.kicad_pcb, i2current.kicad_sch]
2024-05-18 i start order
    [esp32-c3.kicad_sch, i2current.kicad_pcb, i2current.kicad_sch]
2024-06-19 05/24 order
    [i2current.kicad_pcb, i2current.kicad_sch]
2024-08-02 start order
    [i2current.kicad_pcb, i2current.kicad_sch]
2024-09-24 add documentation
    [BOM-i2current.csv, i2current.kicad_pcb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]
2024-09-24 remove unused schematic file
    [esp32-c3.kicad_sch, i2current.kicad_sch]
2024-10-03 add SD test
    [i2current.kicad_sch]
2025-01-06 checkpoint for next rev
    [i2current.kicad_pcb, i2current.kicad_sch]
2025-01-07 finish DRC
    [i2current.kicad_pcb, i2current.kicad_sch]
2025-01-10 before parts
    [i2current.kicad_pcb, i2current.kicad_sch]
2025-01-11 really before order really
    [i2current.kicad_pcb, i2current.kicad_sch]
2025-01-12 01/25 order
    [i2current.kicad_pcb, i2current.kicad_sch]
2025-01-12 add hat template
    [i2current_hat_template.kicad_pcb, i2current_hat_template.kicad_sch]
2025-04-15 add i2current MCU rust FW PoC
2025-04-16 I2C scanner
2025-04-22 PCB next rev checkpoint
    [i2current.kicad_pcb, i2current.kicad_sch]
2025-05-29 may order
    [i2current.kicad_pcb, i2current.kicad_sch]
2025-12-16 fix PD IC serial output not working with esp32
    [main.cpp]
